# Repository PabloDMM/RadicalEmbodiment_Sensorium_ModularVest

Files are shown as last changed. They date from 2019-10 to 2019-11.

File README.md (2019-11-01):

# Sensorium_ModularVest
***Sensorium (Radical Embodiment)*** is a project consisting in a modular illuminated vest that can display abstract information.

***This Repository contains all the files needed to reproduce the device.***
***This Repository is merely destined to the technological part of the project.***
***This Repository makes use of the programs: EagleCad, Arduino IDE, Tensorflow.***

If any other information is needed, please contact with the repository owner (pablodmm.isp@gmail.com) or any of the participants of the project.

## Description

Sensorium is the first prototype for the material tech part of the final project of Gabriel G. Regués. It consist on a modular illuminated vest conformed by an unespecific number of *Arduino* based modules connected to display specific information through an I2C net.

***Watch the Video by pressing the header:***

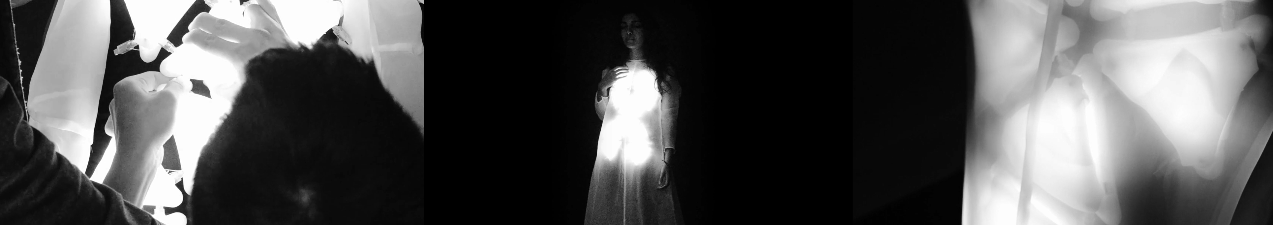
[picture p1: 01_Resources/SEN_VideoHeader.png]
Watch the video (https://vimeo.com/330038499)


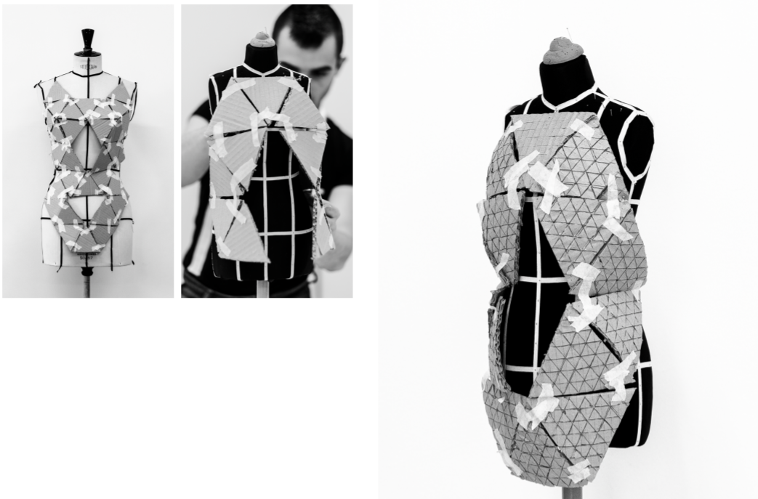
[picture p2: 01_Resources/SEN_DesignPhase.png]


As escribed in the final essay:

*Sensorium - Radical Embodiment - es un proyecto colectivo desarrollado en colaboración por Jaime Remirez de Ganuza, Gonzalo de Torres Sainz, Pablo de Miguel Morales y Gabriel G. Regües.
Este proyecto es una continuación de un proyecto anterior realizado a finales del 2018 por Jaime y Gabriel, al que llamaron El Culto de la Subversión1 y en el que se formularon algunas preguntas que siguen formando parte de este trabajo. El Culto de la Subversión se enfrentaba a la idea de un grupo social en el que se había impuesto una prenda única y se especulaba sobre las posibilidades de transformación de la misma, a medida que los integrantes entraban o dejaban de formar parte del grupo. Los diseñadores investigaban de qué manera cada individuo podía servir creativamente a la creación de los símbolos de representación de un colectivo organizado de forma igualitaria y horizontal. El proyecto se articuló en torno a la creación de una prenda modular, formada por un número determinado de piezas que podían combinarse de distintas maneras. Estas piezas estaban formadas en tela, en la que habían sido impresos unos elementos gráficos. La posibilidades de reconfiguración de la prenda daban lugar a distintas variaciones, tanto en el aspecto formal como gráfico, que representaban la integración o salida de individuos en el grupo.*

## System Overview

The system is based on a I2C net of *Arduino Nano* based modules that control 10 WS212B RGB LEDs each. The aim is to display abstract information incoming from a *Tensorflow* software system running on a PC based on global population database.

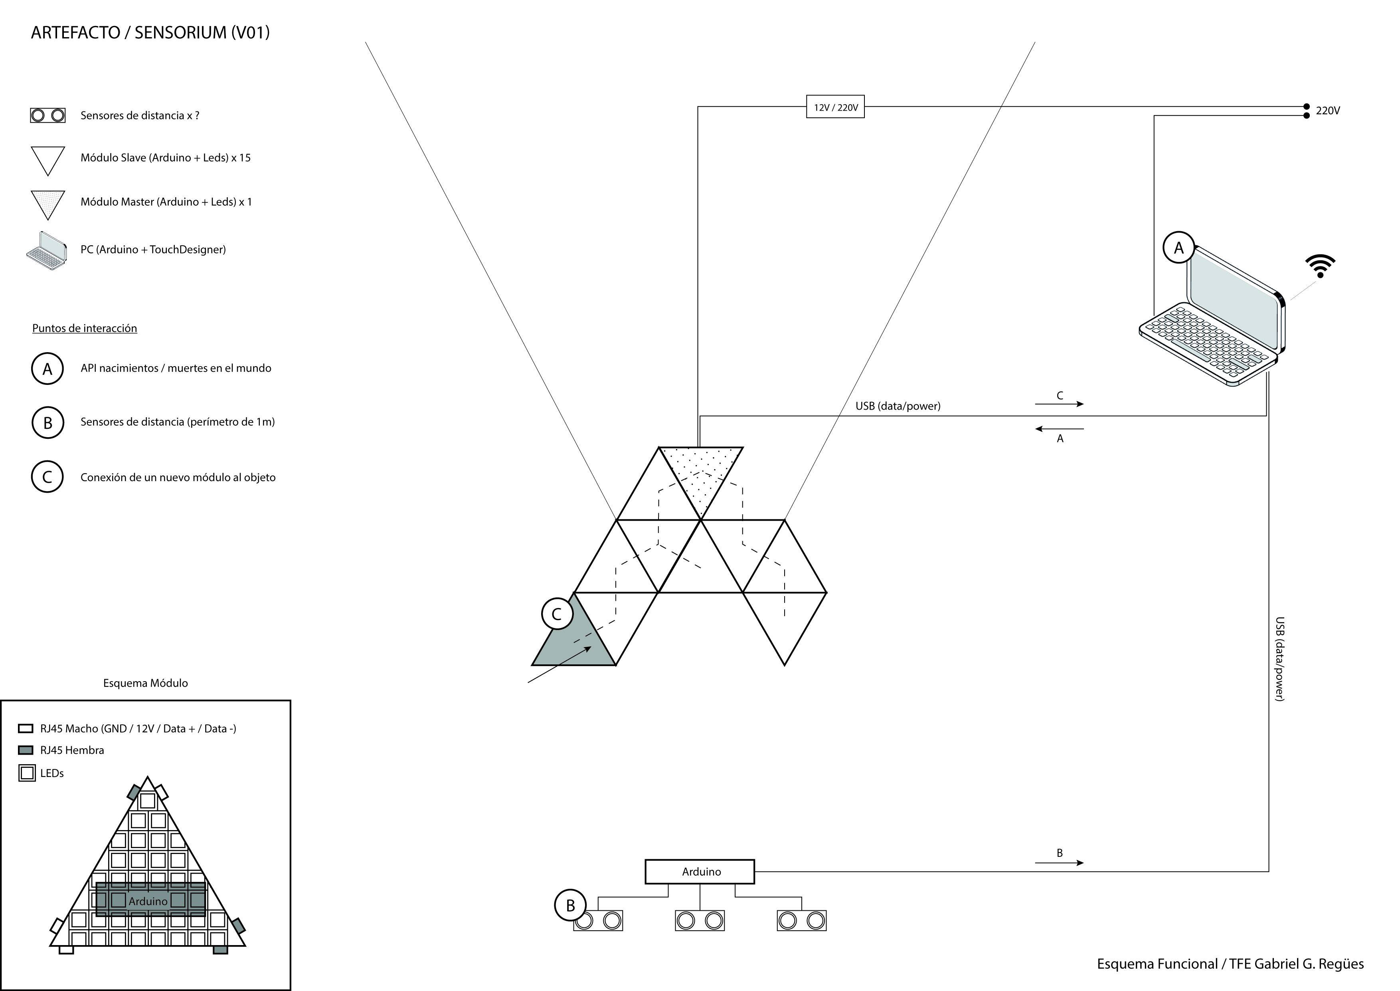
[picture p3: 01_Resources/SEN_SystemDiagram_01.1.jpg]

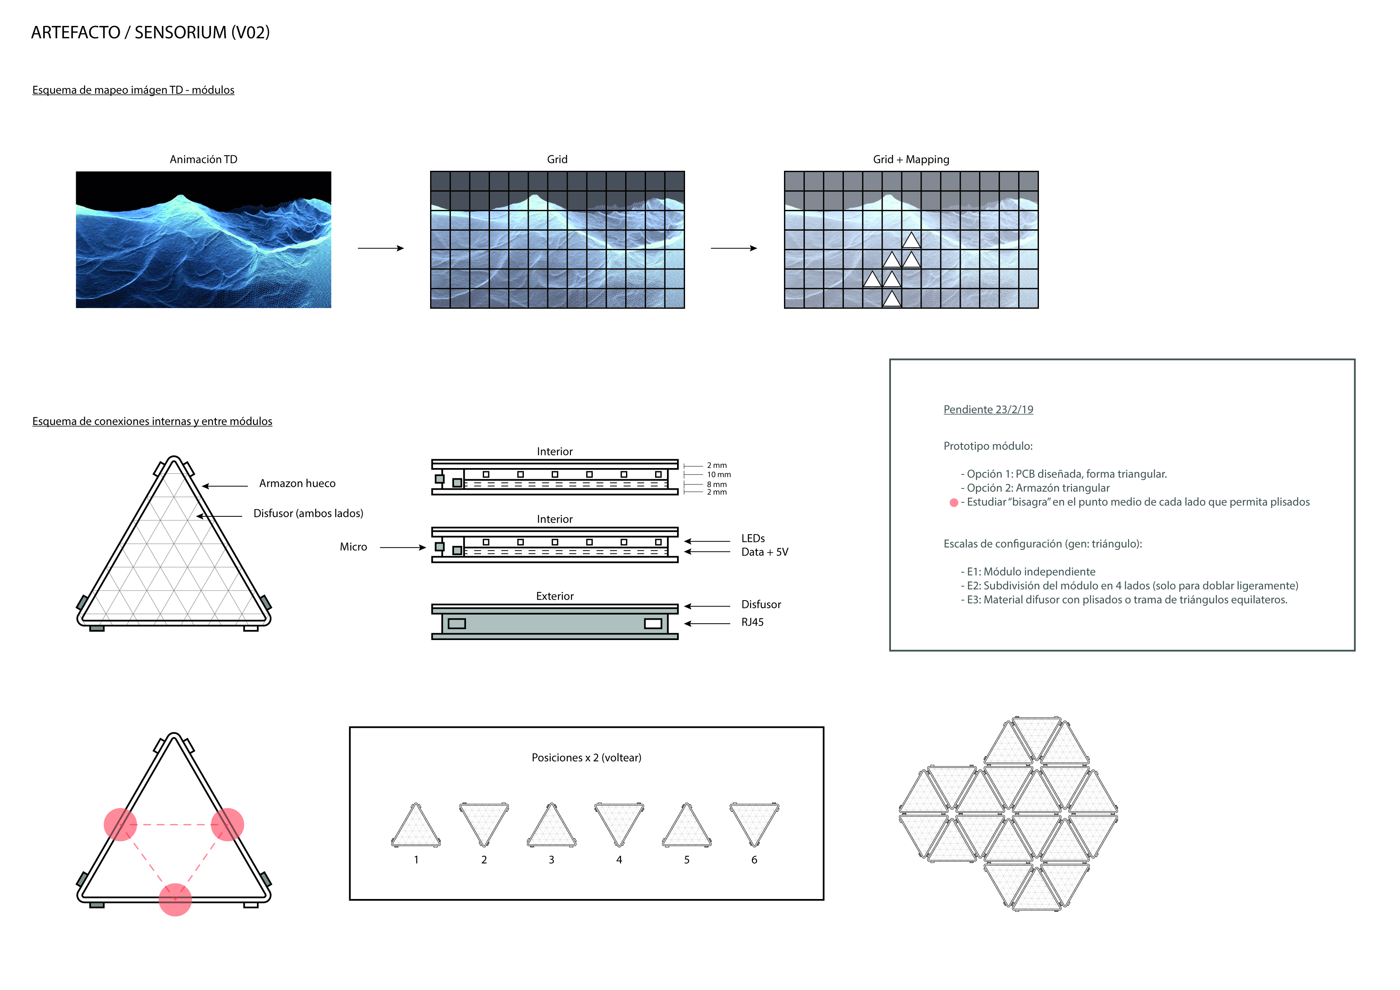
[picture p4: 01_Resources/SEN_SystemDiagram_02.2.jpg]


### Arduino Modules

The Arduino Modules are named *IED_GR_Module_Rev_02*. It consist on a triangular PCB equipped with an *Arduino Nano*, a I2C identification resistor array (8bit based, 254 possible directions) and 10 WS2812B RGB LEDs.

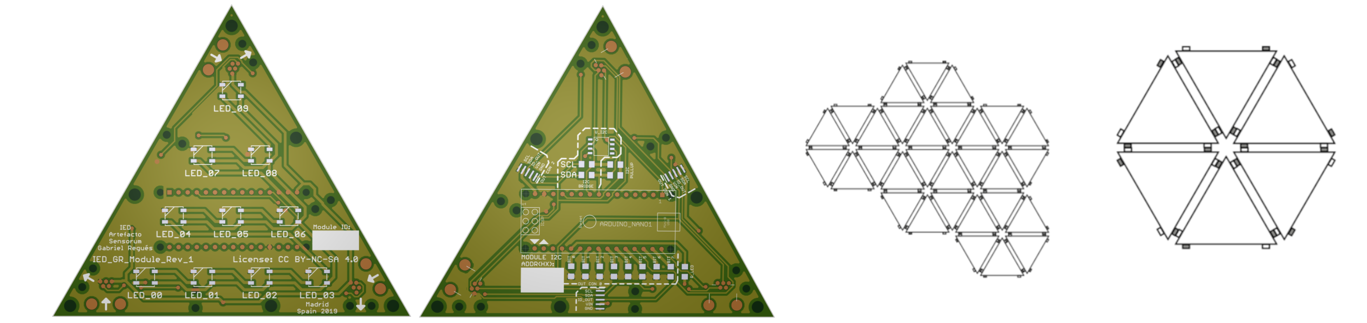
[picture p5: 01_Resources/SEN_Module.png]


Aditionally, it has 3 redundant pairs of miniUSB connectors (both male and female) destined to interconnect an undefined number of modules. The signals present in this connectors are:

* 5V (VCC)
* GND
* SDA (I2C)
* SCL (I2C)

#### Bill of Materials (BOM)
The Module is conformed by the following elements:

* PCB				1	Printed-Circuit-Board	
* Arduino Nano		1	Microprocesador	
* WS2812b  SMD5050	10	RGB LEDs	WS2812B
* Mini USB B female	3	Mini USB B female	
* Mini USB B male	3	Mini USB B male	
* R_DIR_[0:7]		7	10kOhm Resistor. Footprint 1206. Sets the I2C device direction.	
* R_I2C_[0:1]		2	10kOhm Resistor. Footprint 1206. I2C Bus PullUps	

#### PCB Characterictics
The Characteristics of the PCB are the following:

* Dimensions (Square):  100 x 87 mm
* Thickness:            1.6 mm
* Layers:               2 (TOP y BOT)
* Color PCB:            White
* Color Serigraphy:     Black

The PCBs were made through *Elecrow* ( https://www.elecrow.com/ )

#### Prototype Problems
The prototypes have a number of critical mistakes, that can be fixed through the following procedure:

* Step 1: Cut the Signal marked in Blue thorugh the points indicated.
* Step 2: Bypass the signal marked in Green.

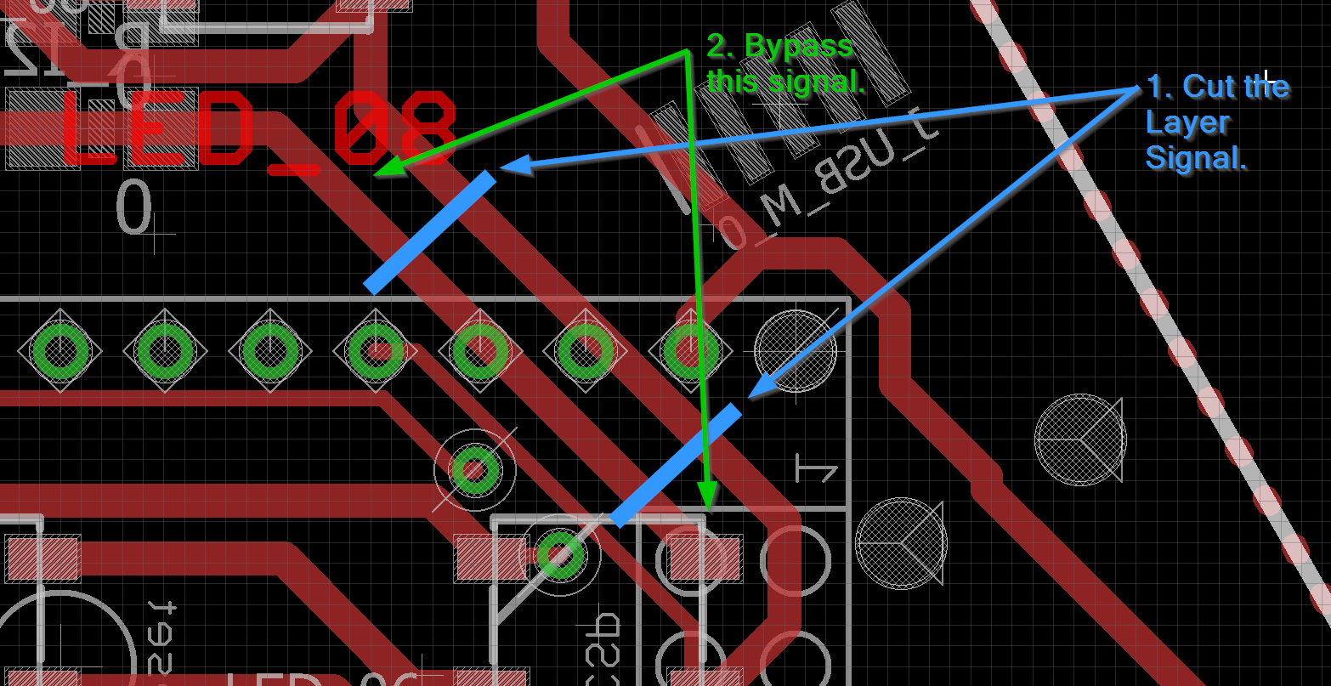
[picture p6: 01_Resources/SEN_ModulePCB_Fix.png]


Anycase, if anyone plans to rebuild the devices, we strongly encourage to contact us to apply a large number of fixes.

#### Software
The modules make use of two *Arduino* sowfwares, one for *I2C Slave* and another for *I2C Master*:

* _SEN_ModuleI2cMaster.ino_: Distributed a long array of data incoming for USB Serial *Tensorflow* Software running in a PC. Only One module of the net performs as *Master*.

* _SEN_ModuleI2cSlave.ino_: Manages 10 WS2812B REG LEDs based of I2C incoming Data.

Additionally, a large number of preliminary *Arduino* programs can be found in the repository, as part of the development.

Please notice the Arduino Nano used need the *Old ATMega328 Bootloader*, not the new one.

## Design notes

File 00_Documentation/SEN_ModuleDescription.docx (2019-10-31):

SENSORIUM_Module_Rev_01

1. Introducción

Este documento recoge una descripción general de la PCB de desarrollo SENSORIUM_Module_Rev_01 , que forma parte del proyecto Sensorium para el TFE de Gabriel G. Regües, alumno del Título Superior de Diseño Gráfico en IED Madrid. Este proyecto se ha hecho en colaboración con Jaime Remirez de Ganuza, Gonzalo de Torres Sainz y Pablo de Miguel Morales. El proyecto consiste en una Instalación interactiva que, mediante la ficción, se propone especular sobre la práctica del Diseño y su potencial como herramienta de transformación social. Parte de esta instalación se compone de una serie de módulos conectables entre si para formar un wereable. Estos módulos son los que contienen la PCB que se describe en este documento.

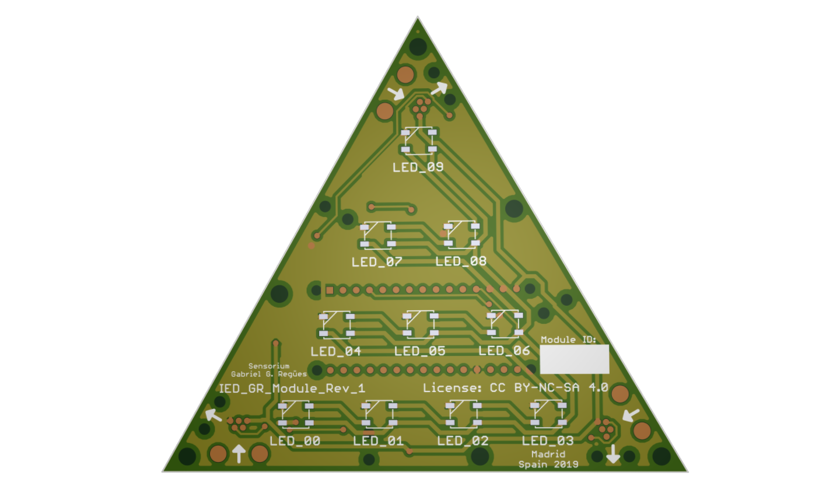
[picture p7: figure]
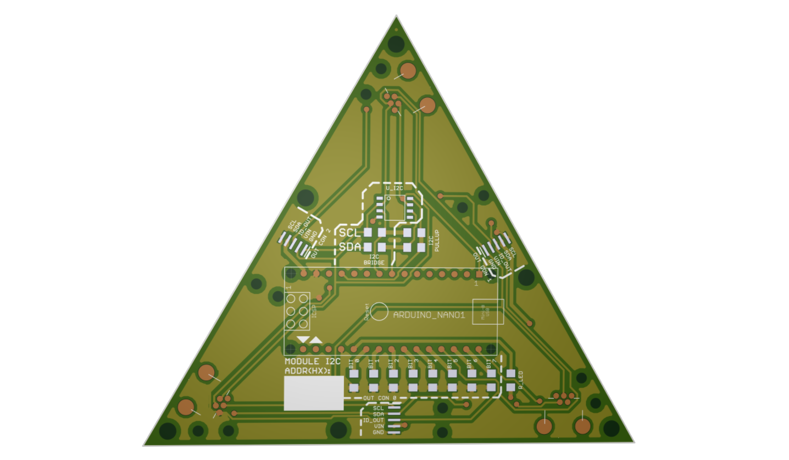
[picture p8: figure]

TOP view BOT view

2. Revisiones

En esta sección se detallan las revisiones realizadas para la SENSORIUM_Module_Rev_01

2.1. Características

En esta sección se describen las características del diseño.

2.1.1. Descripción Funcional

La placa está basada en Arduino Nano. Sus funcionalidades principales son:

- Control de 10 LED WS2812B RGB 5050
- Comunicación i2C entre Arduinos.

2.1.2. Requisitos

2.1.2.1. Arduino Nano

Se ha optado por implementar un Arduino Nano debido a su pequeño tamaño y coste económico.

2.1.1.2.1. Dimensiones y Características Generales

Las características generales de la PCB son:

- Dimensiones: 100 x 87 mm
- Grosor: 1.6 mm
- Capas: 2 (TOP y BOT)
- Color PCB: White
- Color Serigrafía: Black
- Reglas de Diseño Fabricante: Elecrow (http://www.elecrow.com/services/pcb-prototyping/5pcs-2-layer-pcb.html)

2.1.1.2.2. Características Mecánicas

El plano mecánico corresponde a:

(Meter plano)

Donde los DRILLS de sujección son ( ) y se encuentran en las posiciones [x / y] , [x / y] , [x / y] , [x / y] (en mm) siendo la posición [0/0] la esquina inferior izquierda.

2.1.1.3. Bill of Materials (BOM)

Los componentes que forman parte de la PCB están documentados en IED_TFG_BOM_Sensorium.

A continuación se presenta una tabla resumen:

ID | Q. | Descripción | PN
PCB | 1 | Printed-Circuit-Board
Arduino Nano | 1 | Microprocesador
WS2812b SMD5050 | 10 | RGB LEDs | WS2812B
Mini USB B female | 3 | Mini USB B female
Mini USB B male | 3 | Mini USB B male
R_DIR_[0:7] | 7 | 10kOhm Resistor. Footprint 1206. Sets the I2C device direction.
R_I2C_[0:1] | 2 | 10kOhm Resistor. Footprint 1206. I2C Bus PullUps

2.1.1.4. Descripción de Circuitos Concretos

En esta sección se describen en detalle circuitos concretos con un interés particular para el desarrollador.

2.1.1.2.1. Pinout Arduino

Se detalla a continuación la relación de pines del Arduino Nano, que modela las señales de control de todo el circuito.

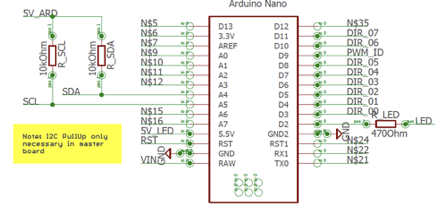
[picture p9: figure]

Arduino IO Pin | Señal | Descripción
D13 | -
3.3V | -
AREF | -
A0 | -
A1 | -
A2 | -
A3 | -
A4 | -
A5 | -
A6 | -
A7 | -
5.5V | 5V_LED
RST | RST
GND | GND
RAW | VIN
D12 | -
D11 | DIR_07
D10 | DIR_06
D9 | PWM_ID
D8 | DIR_05
D7 | DIR_04
D6 | DIR_03
D5 | DIR_02
D4 | DIR_01
D3 | R_LED 470 Ohm
D2 | DIR_00
GND2 | -
RST1 | -
RX1 | -
TXO | -

2.1.1.2.2. Circuito Conectores Mini USB B para conectar módulos

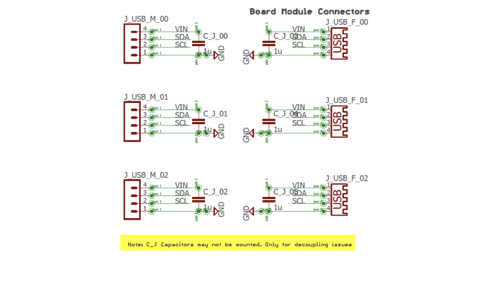
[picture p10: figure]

2.1.1.2.3. Circuito WS2812B RGB LEDs

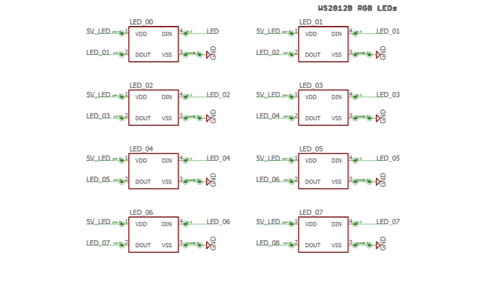
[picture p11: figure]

2.1.1.2.4. Circuito i2C Dir Resistors

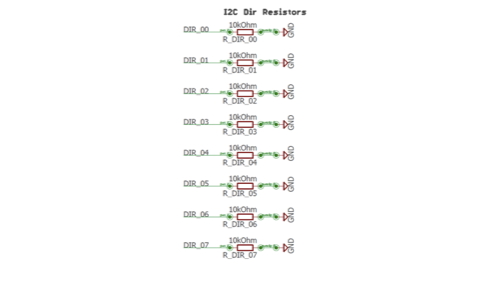
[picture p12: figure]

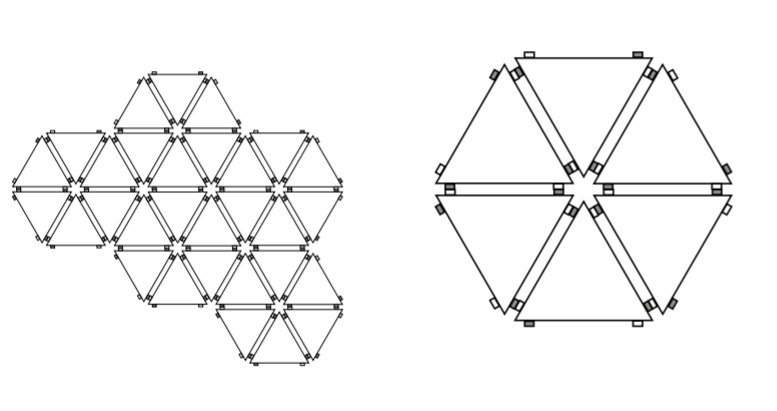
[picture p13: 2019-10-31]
01_Resources/SEN_ModuleConnectionDiagram.png

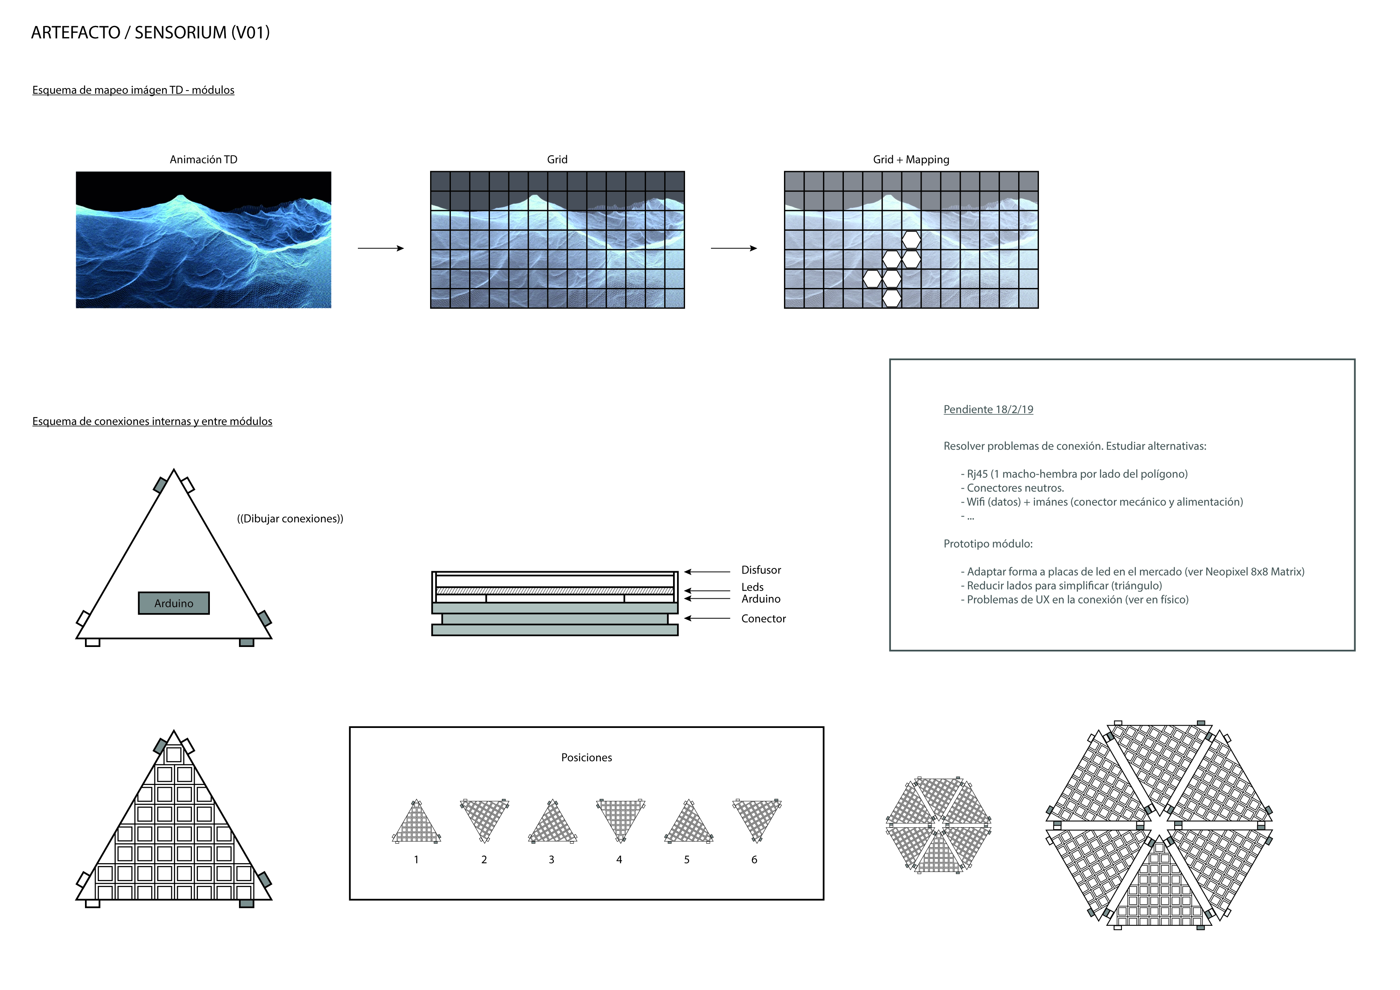
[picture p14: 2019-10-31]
00_Documentation/SEN_SystemDiagram_01.2.jpg

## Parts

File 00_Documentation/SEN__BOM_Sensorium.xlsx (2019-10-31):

BOM |  |  |  |  |  |  | PRICING
ID | Status | Description | Manufacturer | PN | Footprint | Q. | PCs in Pack | Pack Q. | Pack Price (€) | PCs Extra | Total Item | Provider
ELECTRONICS
PCB |  | Printed-Circuit-Board | ELECROW | - | - | 1 | 40 | 01 | €76.82 | 22 | €84.61 | https://www.elecrow.com/pcb-manufacturing.html
ARDUINO NANO |  | Arduino-Nano | TENSTAR ROBOT | - | - | 1 | 40 | 01 | €72.59 | 22 | €72.59 | https://es.aliexpress.com/store/product/Freeshipping-Nano-3-0-controller-compatible-for-arduino-nano-CH340-USB-driver-NO-CABLE/731260_32341832857.html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
WS2812b SMD5050 |  | LEDs | BTF-LIGHTING |  |  | 10 | 500 | 01 | €31.09 | 320 | €31.09 | https://es.aliexpress.com/item/10-1000pcs-WS2812B-4pins-5050-SMD-Black-White-version-WS2812-Individually-Addressable-Digital-RGB-LED-Chip/32453497583.html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
Mini USB tipo B hembra |  | Mini USB tipo B hembra | ZLinKJ |  |  | 3 | 120 | 01 | €7.23 | 66 | €7.23 | https://es.aliexpress.com/store/product/10pcs-Micro-USB-Port-Sockect-Plug-Male-to-Female-Mini-USB-Jack-Front-2Feet-5-PIN/4287020_32888277248.html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
Mini USB tipo B macho |  | Mini USB tipo B macho | OOTDTY |  |  | 3 | 60 | 02 | €31.32 | 66 | €62.64 | https://es.aliexpress.com/store/product/1-PC-Short-USB2-0-Extension-Cable-A-Male-to-Mini-5-pin-B-Male-USB/2793067_32803810965.html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
 |  |  |  |  |  | 0 | 1 | 00 | €0.00 | 0 | €0.00
 |  |  |  |  |  | 0 | 1 | 00 | €0.00 | 0 | €0.00
 |  |  |  |  |  | 0 | 1 | 00 | €0.00 | 0 | €0.00
FRAME
 |  |  |  |  |  | 0 | 1 | 00 | €0.00 | 0 | €0.00
 |  |  |  |  |  | 0 | 1 | 00 | €0.00 | 0 | €0.00
 |  |  |  |  |  | 0 | 1 | 00 | €0.00 | 0 | €0.00
DIFUSSER
 |  |  |  |  |  | 0 | 1 | 00 | €0.00 | 0 | €0.00
 |  |  |  |  |  | 0 | 1 | 00 | €0.00 | 0 | €0.00
 |  |  |  |  | Total Expenses |  |  |  |  |  | €258.16
 |  |  |  |  | System Q. | 18
*Envío desde Madrid 5-7 días
Caja: silicona para molde, resina, filoflex...
Difusor: Tela, plástico, gel, vinilo....

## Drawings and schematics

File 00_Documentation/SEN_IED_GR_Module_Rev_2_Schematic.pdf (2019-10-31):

# 0 GND GND

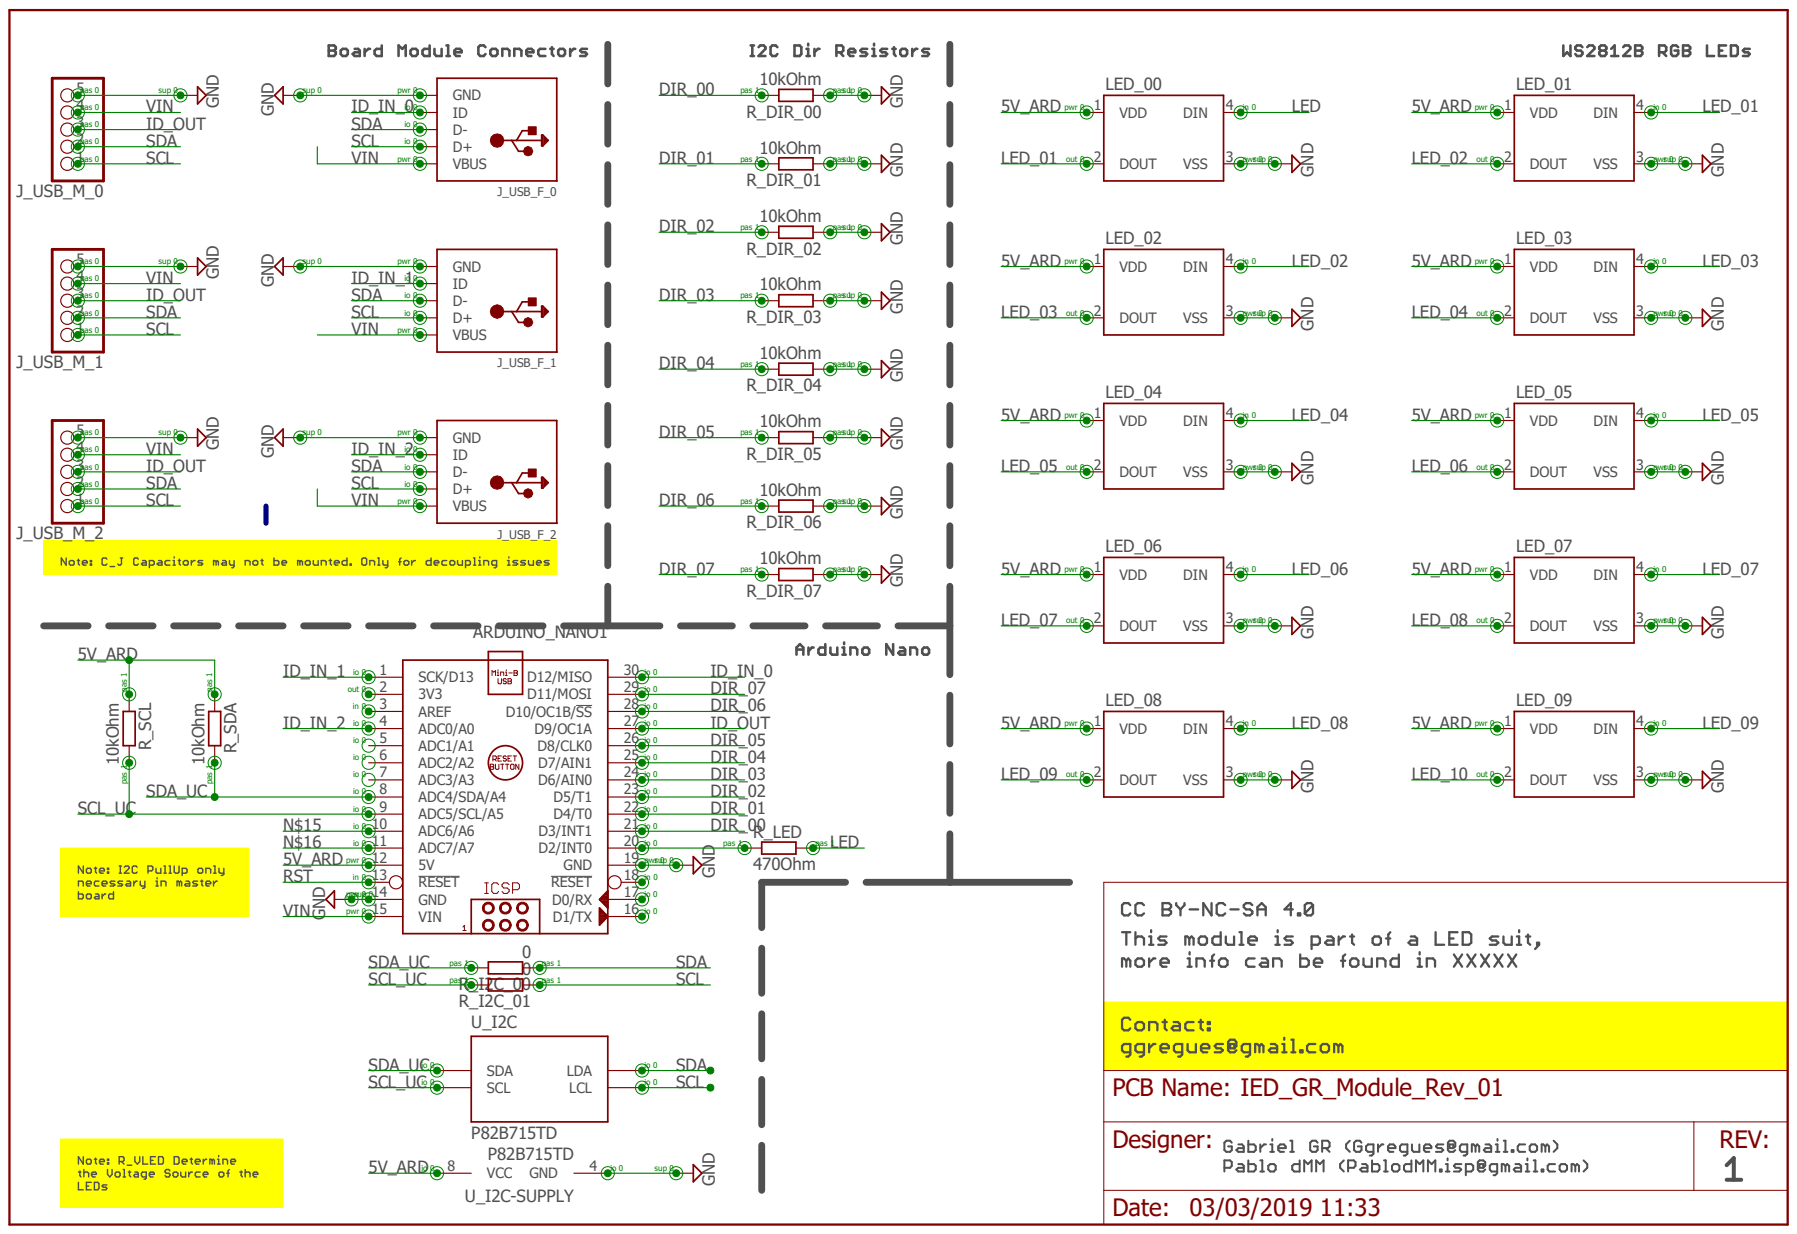
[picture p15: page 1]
470Ohm; 10kOhm; GND; GND GND; GND GND GND; VDD 1; DOUT 2; VSS; DIN; 4 LED_00 R_SCL; R_SDA; 4 LED_01; 4 LED_02; 4 LED_03; 4 LED_04; 4 LED_05; 4 LED_06; 4 LED_07; 4 LED_08; 4 LED_09; R_LED; R_DIR_00; R_DIR_01; R_DIR_02; R_DIR_03; R_DIR_04; R_DIR_05; R_DIR_06; R_DIR_07; 17 RESET; 18 GND; 19 D2/INT0; 20 D3/INT1; 23 D6/AIN0; 24 D7/AIN1; 25 D8/CLK0; 28 D11/MOSI; 29 D12/MISO; 30 SCK/D13 1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

GND GND GND 10kOhm 10kOhm GND GND GND GND GND GND GND GND GND

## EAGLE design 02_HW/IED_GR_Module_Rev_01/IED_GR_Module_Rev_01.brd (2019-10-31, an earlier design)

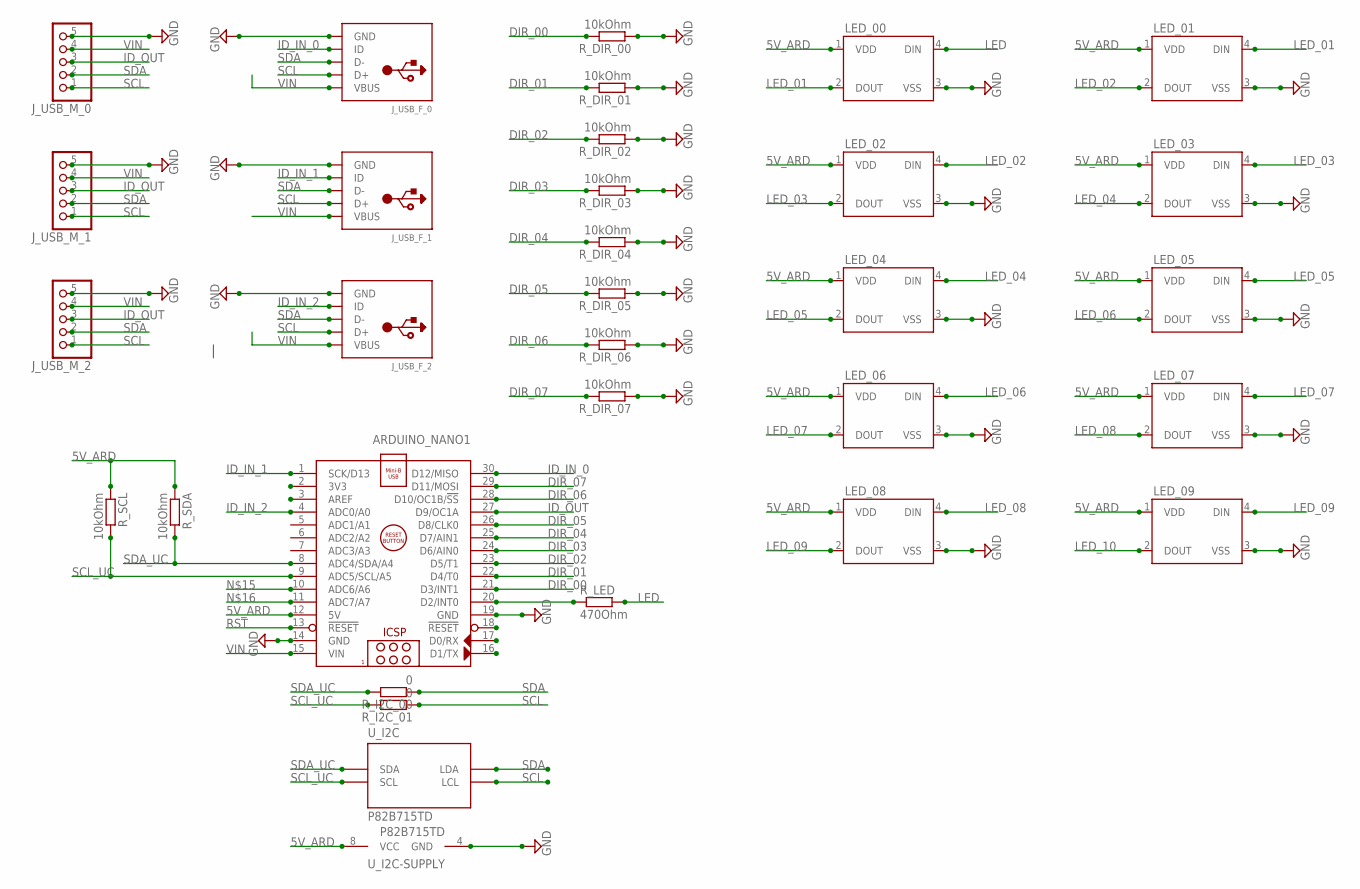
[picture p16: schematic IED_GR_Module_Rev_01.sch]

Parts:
ARDUINO_NANO1: ARDUINO_NANO
J_USB_F_0, J_USB_F_1, J_USB_F_2: USBTHM; USB-MINIB-THM
J_USB_M_0, J_USB_M_1, J_USB_M_2: HEADER-1X51.27MM; 1X05_1.27MM
LED_00, LED_01, LED_02, LED_03, LED_04, LED_05, LED_06, LED_07, LED_08, LED_09: WS2812B
R_DIR_00, R_DIR_01, R_DIR_02, R_DIR_03, R_DIR_04, R_DIR_05, R_DIR_06, R_DIR_07: 10kOhm; R1206
R_I2C_00, R_I2C_01: 0; R1206
R_LED: 470Ohm; R1206
R_SCL: 10kOhm; R1206
R_SDA: 10kOhm; R1206
U_I2C: P82B715TD; SOIC-8

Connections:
5V_ARD: ARDUINO_NANO1.12 (5V), LED_00.1 (VDD), LED_01.1 (VDD), LED_02.1 (VDD), LED_03.1 (VDD), LED_04.1 (VDD), LED_05.1 (VDD), LED_06.1 (VDD), LED_07.1 (VDD), LED_08.1 (VDD), LED_09.1 (VDD), R_SCL.1, R_SDA.1, U_I2C.8 (VCC)
DIR_00: ARDUINO_NANO1.21 (D3/INT1), R_DIR_00.2
DIR_01: ARDUINO_NANO1.22 (D4/T0), R_DIR_01.2
DIR_02: ARDUINO_NANO1.23 (D5/T1), R_DIR_02.2
DIR_03: ARDUINO_NANO1.24 (D6/AIN0), R_DIR_03.2
DIR_04: ARDUINO_NANO1.25 (D7/AIN1), R_DIR_04.2
DIR_05: ARDUINO_NANO1.26 (D8/CLK0), R_DIR_05.2
DIR_06: ARDUINO_NANO1.28 (D10/OC1B/!SS), R_DIR_06.2
DIR_07: ARDUINO_NANO1.29 (D11/MOSI), R_DIR_07.2
GND: ARDUINO_NANO1.14 (GND), ARDUINO_NANO1.19 (GND), J_USB_F_0.GND, J_USB_F_1.GND, J_USB_F_2.GND, J_USB_M_0.5, J_USB_M_1.5, J_USB_M_2.5, LED_00.3 (VSS), LED_01.3 (VSS), LED_02.3 (VSS), LED_03.3 (VSS), LED_04.3 (VSS), LED_05.3 (VSS), LED_06.3 (VSS), LED_07.3 (VSS), LED_08.3 (VSS), LED_09.3 (VSS), R_DIR_00.1, R_DIR_01.1, R_DIR_02.1, R_DIR_03.1, R_DIR_04.1, R_DIR_05.1, R_DIR_06.1, R_DIR_07.1, U_I2C.4 (GND)
ID_IN_0: ARDUINO_NANO1.30 (D12/MISO), J_USB_F_0.ID
ID_IN_1: ARDUINO_NANO1.1 (SCK/D13), J_USB_F_1.ID
ID_IN_2: ARDUINO_NANO1.4 (ADC0/A0), J_USB_F_2.ID
ID_OUT: ARDUINO_NANO1.27 (D9/OC1A), J_USB_M_0.3, J_USB_M_1.3, J_USB_M_2.3
LED: LED_00.4 (DIN), R_LED.2
LED_01: LED_00.2 (DOUT), LED_01.4 (DIN)
LED_02: LED_01.2 (DOUT), LED_02.4 (DIN)
LED_03: LED_02.2 (DOUT), LED_03.4 (DIN)
LED_04: LED_03.2 (DOUT), LED_04.4 (DIN)
LED_05: LED_04.2 (DOUT), LED_05.4 (DIN)
LED_06: LED_05.2 (DOUT), LED_06.4 (DIN)
LED_07: LED_06.2 (DOUT), LED_07.4 (DIN)
LED_08: LED_07.2 (DOUT), LED_08.4 (DIN)
LED_09: LED_08.2 (DOUT), LED_09.4 (DIN)
LED_10: LED_09.2 (DOUT)
LED_OUT: ARDUINO_NANO1.20 (D2/INT0), R_LED.1
RST: ARDUINO_NANO1.13 (!RESET)
SCL: J_USB_F_0.D+, J_USB_F_1.D+, J_USB_F_2.D+, J_USB_M_0.1, J_USB_M_1.1, J_USB_M_2.1, R_I2C_01.1, U_I2C.2 (LCL)
SCL_UC: ARDUINO_NANO1.9 (ADC5/SCL/A5), R_I2C_01.2, R_SCL.2, U_I2C.3 (SCL)
SDA: J_USB_F_0.D-, J_USB_F_1.D-, J_USB_F_2.D-, J_USB_M_0.2, J_USB_M_1.2, J_USB_M_2.2, R_I2C_00.1, U_I2C.7 (LDA)
SDA_UC: ARDUINO_NANO1.8 (ADC4/SDA/A4), R_I2C_00.2, R_SDA.2, U_I2C.6 (SDA)
VIN: ARDUINO_NANO1.15 (VIN), J_USB_F_0.VBUS, J_USB_F_1.VBUS, J_USB_F_2.VBUS, J_USB_M_0.4, J_USB_M_1.4, J_USB_M_2.4

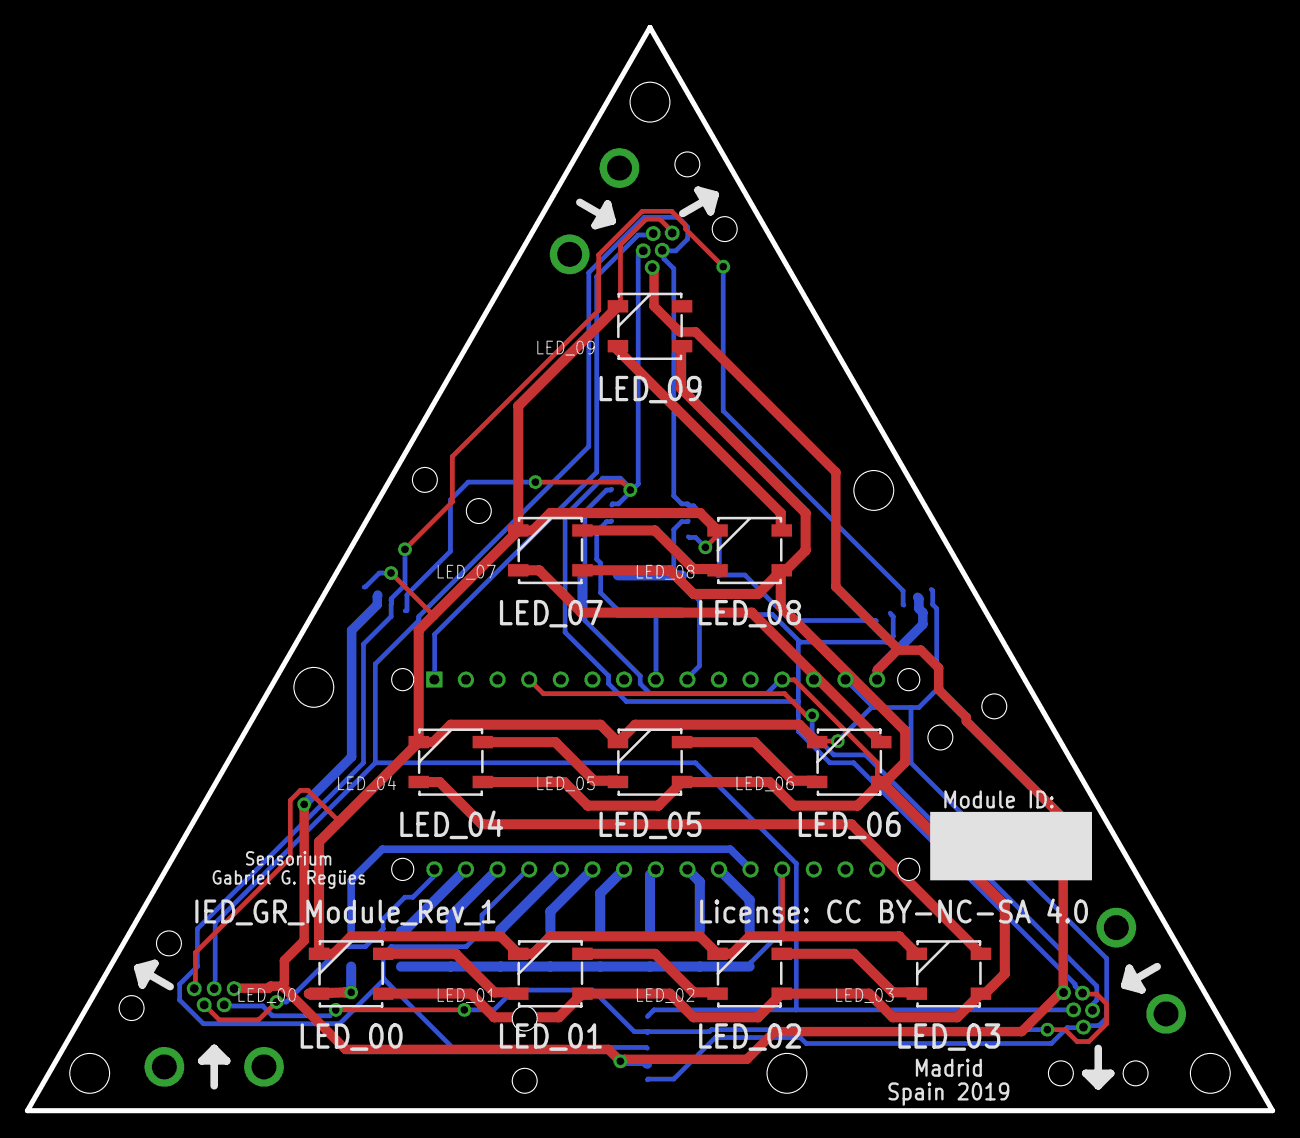
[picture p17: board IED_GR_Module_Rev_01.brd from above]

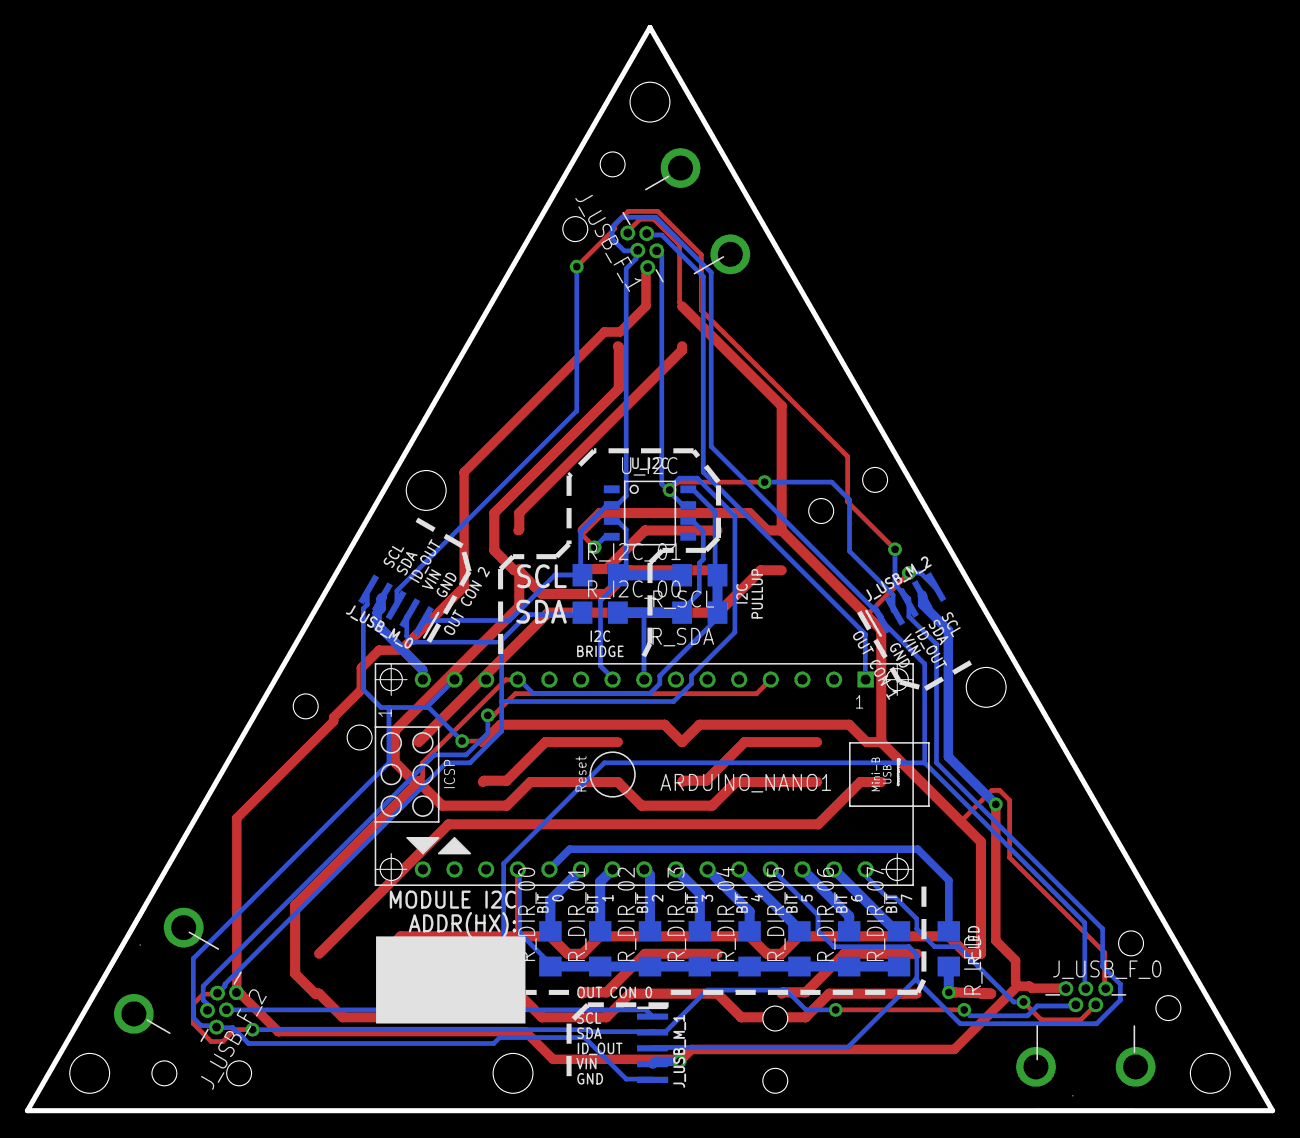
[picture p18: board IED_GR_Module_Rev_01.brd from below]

Board: 2 copper layers, 100.0 x 87.0 mm, 31 parts (21 on the bottom side), 30 nets.

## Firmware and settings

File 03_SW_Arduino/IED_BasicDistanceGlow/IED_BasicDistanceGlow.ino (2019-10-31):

// Library Import
#include <Adafruit_NeoPixel.h>
#include <MIDIUSB.h>
//#include <HCSR04.h>
//#include <hcsr04.h>
#include <HCSR04.h>


// -----------------------------------------------------------------------------------------------------------------------------------------
// ---------------------------------------------------LED Gamma Correction LUT--------------------------------------------------------------
// -----------------------------------------------------------------------------------------------------------------------------------------
const int GC[256] = {
    0,  0,  0,  0,  0,  0,  0,  0,  0,  0,  0,  0,  0,  0,  0,  0,
    0,  0,  0,  0,  0,  0,  0,  0,  0,  0,  0,  0,  1,  1,  1,  1,
    1,  1,  1,  1,  1,  1,  1,  1,  1,  2,  2,  2,  2,  2,  2,  2,
    2,  3,  3,  3,  3,  3,  3,  3,  4,  4,  4,  4,  4,  5,  5,  5,
    5,  6,  6,  6,  6,  7,  7,  7,  7,  8,  8,  8,  9,  9,  9, 10,
   10, 10, 11, 11, 11, 12, 12, 13, 13, 13, 14, 14, 15, 15, 16, 16,
   17, 17, 18, 18, 19, 19, 20, 20, 21, 21, 22, 22, 23, 24, 24, 25,
   25, 26, 27, 27, 28, 29, 29, 30, 31, 32, 32, 33, 34, 35, 35, 36,
   37, 38, 39, 39, 40, 41, 42, 43, 44, 45, 46, 47, 48, 49, 50, 50,
   51, 52, 54, 55, 56, 57, 58, 59, 60, 61, 62, 63, 64, 66, 67, 68,
   69, 70, 72, 73, 74, 75, 77, 78, 79, 81, 82, 83, 85, 86, 87, 89,
   90, 92, 93, 95, 96, 98, 99,101,102,104,105,107,109,110,112,114,
  115,117,119,120,122,124,126,127,129,131,133,135,137,138,140,142,
  144,146,148,150,152,154,156,158,160,162,164,167,169,171,173,175,
  177,180,182,184,186,189,191,193,196,198,200,203,205,208,210,213,
  215,218,220,223,225,228,231,233,236,239,241,244,247,249,252,255 };

// -----------------------------------------------------------------------------------------------------------------------------------------
// ---------------------------------------------------Custom Configuration Structs----------------------------------------------------------
// -----------------------------------------------------------------------------------------------------------------------------------------
// Generated Structures (struct)
struct LEDCOL{
  int red;
  int green;
  int blue;
};

// -----------------------------------------------------------------------------------------------------------------------------------------
// ---------------------------------------------------General Constant Definition-----------------------------------------------------------
// -----------------------------------------------------------------------------------------------------------------------------------------
// PIN DEFINITION
// Digital Pin Definitions
const int  LED    = 2;
const int  SW_0   = 7;
const int  SW_1   = 8;
const int  CH_0   = 0;
const int  CH_1   = 1;
const int  CH_2   = 2;
const int  CH_3   = 3;
const int  MUX_A  = 3;
const int  MUX_B  = 4;
const int  MUX_C  = 5;
const int  MUX_D  = 6;
const int  SW_Q   = 16;

// Constant Definition
const bool ON                 =   1;         // General ON value
const bool OFF                =   0;         // General OFF value

const bool UP                 =   1;         // General UP Fade Direction value
const bool DOWN               =   0;         // General DOWN Fade Direction value

const int LED_INNER_Q        =   4;         
const int LED_OUTER_Q        =   12;


const int FADESTEPS_C         =   100; // GENERAL FadeSteps
const int FADEDELAY_C         =   25; // GENERAL FadeDelay

LEDCOL GEN_OFF    = {GC[255], GC[255],  GC[255]};  // SW_GENERAL OFF LED COLOR
LEDCOL DIST_ON    = {GC[255], GC[0],    GC[200]};  // SW_SCALE ON LED COLOR
LEDCOL DIST_OFF   = {GC[0],   GC[0],     GC[0]};  // SW_MODE ON LED COLOR

const int INNER_LED[4]  = {5, 6, 9, 10};
const int OUTER_LED[12] = {0, 1, 2, 3, 4, 7, 8, 11, 12, 13, 14, 15};

const int THR_DISTANCE  = 40;

bool distanceStatus = OFF;
bool fadeDirection = UP;

Adafruit_NeoPixel LEDSTR = Adafruit_NeoPixel(SW_Q, LED, NEO_RGB + NEO_KHZ800);

HCSR04 DISTANCE(6,7);//initialisation class HCSR04 (trig pin , echo pin)

void setup() {
  // Baudrate Set
  Serial.begin(115200); 
  // LED Stripe Initialization
  LEDSTR.begin();
  LEDSTR.show();
  // Set Pin Modes
  pinMode(MUX_A, OUTPUT);
  pinMode(MUX_B, OUTPUT);
  pinMode(MUX_C, OUTPUT);
  pinMode(MUX_D, OUTPUT);

  //LED_FADE_INIT(0, 0, 0, CH_LED[0][1], CH_LED[0][0], CH_LED[0][2], 10, 80);
}

void loop() {  
  for(int currentStep = 0; currentStep < FADESTEPS_C; currentStep++){
    distanceStatus = get_distanceStatus();
    Serial.println(distanceStatus);
    switch(distanceStatus){
      case OFF:
        //Serial.println("LED OFF");
        LED_GLOWOUT(DIST_OFF, GEN_OFF, FADESTEPS_C, FADEDELAY_C, currentStep, fadeDirection);
        break;
      case ON:     
        //Serial.println("LED ON");
        LED_GLOWOUT(DIST_ON, GEN_OFF, FADESTEPS_C, (FADEDELAY_C/5), currentStep, fadeDirection);
        break;
      break;
    }
  }
  fadeDirection = !fadeDirection;   // Switch Fade Glow Direction
}

void LED_GLOWOUT(LEDCOL COL_ON, LEDCOL COL_OFF, int FS, int FD, int Step, bool fadeDir){
  int RDiff = (COL_OFF.red-COL_ON.red);
  int GDiff = (COL_OFF.green-COL_ON.green);
  int BDiff = (COL_OFF.blue-COL_ON.blue);
  //for(int Step = 0; Step < FS; Step++){
  if(fadeDir == UP){
    for(int i = 0; i < LED_INNER_Q; i++){
      //Serial.println(i);
      LEDSTR.setPixelColor(INNER_LED[i], (COL_OFF.green - ((GDiff/FS)*(FS-Step))), (COL_OFF.red - ((RDiff/FS)*(FS-Step))), (COL_OFF.blue - ((BDiff/FS)*(FS-Step))));
    }
    for(int i = 0; i < LED_OUTER_Q; i++){
      //Serial.println(i);
      LEDSTR.setPixelColor(OUTER_LED[i], (COL_OFF.green - ((GDiff/FS)*(Step))), (COL_OFF.red - ((RDiff/FS)*(Step))), (COL_OFF.blue - ((BDiff/FS)*(Step))));
    }
    LEDSTR.show(); // Update LEDs 
    delay(FD);
  }

  else if(fadeDir == DOWN){
    for(int i = 0; i < LED_INNER_Q; i++){
      //Serial.println(i);
      LEDSTR.setPixelColor(INNER_LED[i], (COL_OFF.green - ((GDiff/FS)*(Step))), (COL_OFF.red - ((RDiff/FS)*(Step))), (COL_OFF.blue - ((BDiff/FS)*(Step))));
    }
    for(int i = 0; i < LED_OUTER_Q; i++){
      //Serial.println(i);
      LEDSTR.setPixelColor(OUTER_LED[i], (COL_OFF.green - ((GDiff/FS)*(FS-Step))), (COL_OFF.red - ((RDiff/FS)*(FS-Step))), (COL_OFF.blue - ((BDiff/FS)*(FS-Step))));
    }
    LEDSTR.show(); // Update LEDs 
    delay(FD);
  }
}

bool get_distanceStatus(){
  bool newState = distanceStatus;
  switch(distanceStatus){
    case OFF:      
      if(DISTANCE.dist() <= THR_DISTANCE){
        Serial.println("OFF to ON");
        newState = ON;
      }
      break;
    case ON:      
      if(DISTANCE.dist() > THR_DISTANCE){
        newState = OFF;
        Serial.println("ON to OFF");
      }
      break;
  }
  return newState;
}

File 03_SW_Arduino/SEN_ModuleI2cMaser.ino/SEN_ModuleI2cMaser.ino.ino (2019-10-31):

/*
 * @file      SEN_ModuleI2cMaser.ino
 * 
 * @authors   Pablo dMM, Gabriel GR (based on Nicholas Zambetti <http://www.zambetti.com> )
 * @date      June 2019
 * @brief     This code correspond to the I2C Slave Master of the Sensorium project, please refer to the repository for more information: https://github.com/PabloDMM/Sensorium_ModularVest
 */

// Libraries
#include <Adafruit_NeoPixel.h>
#include <Wire.h>

// Pin definition
const int LED_PIN    = 2;
const int DIR_00_PIN = 3;
const int DIR_01_PIN = 4;
const int DIR_02_PIN = 5;
const int DIR_03_PIN = 6;
const int DIR_04_PIN = 7;
const int DIR_05_PIN = 8;
const int DIR_06_PIN = 10;
const int DIR_07_PIN = 11;

const byte LEDWHITEINIT       = 50;     // INIT White LED value
const byte LEDWHITE_MINVAR    = 5;      // Minimum variation of LED value
const byte LEDWHITE_MAXVAR    = 50;     // Maximum variation of LED value
const byte LEDWHITE_MINDELAY  = 150;    // Minimum delay between steps
const byte LEDWHITE_MAXDELAY  = 300;    // Mazimum delay between steps

const int FADESTEPS_C         =   25; // GENERAL FadeSteps
const int FADEDELAY_C         =   500; // GENERAL FadeDelay

// Gamma Correction (GC) LUT
const byte GC[256] = {
    0,  0,  0,  0,  0,  0,  0,  0,  0,  0,  0,  0,  0,  0,  0,  0,
    0,  0,  0,  0,  0,  0,  0,  0,  0,  0,  0,  0,  1,  1,  1,  1,
    1,  1,  1,  1,  1,  1,  1,  1,  1,  2,  2,  2,  2,  2,  2,  2,
    2,  3,  3,  3,  3,  3,  3,  3,  4,  4,  4,  4,  4,  5,  5,  5,
    5,  6,  6,  6,  6,  7,  7,  7,  7,  8,  8,  8,  9,  9,  9, 10,
   10, 10, 11, 11, 11, 12, 12, 13, 13, 13, 14, 14, 15, 15, 16, 16,
   17, 17, 18, 18, 19, 19, 20, 20, 21, 21, 22, 22, 23, 24, 24, 25,
   25, 26, 27, 27, 28, 29, 29, 30, 31, 32, 32, 33, 34, 35, 35, 36,
   37, 38, 39, 39, 40, 41, 42, 43, 44, 45, 46, 47, 48, 49, 50, 50,
   51, 52, 54, 55, 56, 57, 58, 59, 60, 61, 62, 63, 64, 66, 67, 68,
   69, 70, 72, 73, 74, 75, 77, 78, 79, 81, 82, 83, 85, 86, 87, 89,
   90, 92, 93, 95, 96, 98, 99,101,102,104,105,107,109,110,112,114,
  115,117,119,120,122,124,126,127,129,131,133,135,137,138,140,142,
  144,146,148,150,152,154,156,158,160,162,164,167,169,171,173,175,
  177,180,182,184,186,189,191,193,196,198,200,203,205,208,210,213,
  215,218,220,223,225,228,231,233,236,239,241,244,247,249,252,255 };


const byte LED_Q        = 10;
const byte MAX_MODULE   = 40;

const byte MIN_I2CDIR   = 8;

const byte ON    = 1;
const byte OFF   = 0;

// Generated Structures (struct)
struct LEDCOL{
  byte red;
  byte green;
  byte blue;
};

// Generated Structures (struct)
struct MODULE{
  byte i2cDir;
  byte detected;
};

// Global Variables
Adafruit_NeoPixel LEDSTR = Adafruit_NeoPixel(LED_Q, LED_PIN, NEO_GRB + NEO_KHZ800);
byte modulesPresent = 1;
//char inputBuffer[LED_Q * MAX_MODULE];
MODULE devices[MAX_MODULE];
LEDCOL GEN_ON    = {GC[255], GC[255],  GC[255]};  
byte ledWhite[LED_Q] = {LEDWHITEINIT, LEDWHITEINIT, LEDWHITEINIT, LEDWHITEINIT, LEDWHITEINIT, LEDWHITEINIT,LEDWHITEINIT,LEDWHITEINIT,LEDWHITEINIT,LEDWHITEINIT};


void setup() {
  Serial.begin(115200);
  Serial.setTimeout(500);
  
  // Initialice devices to OFF
  for(int i = 0; i < MAX_MODULE; i++){
    devices[i].i2cDir = (MIN_I2CDIR + i);
    devices[i].detected = OFF;
  }
  LEDSTR.begin();
  LEDSTR.show(); // Initialize all pixels to 'off'
  Wire.begin(); // join i2c bus (address optional for master)
}


void loop(){
  char inputBuffer[LED_Q * modulesPresent];
  if(Serial.available() > 0) {
    Serial.readBytes(inputBuffer, (LED_Q * modulesPresent));
  }

  // Turn on self lights
  for(int ledIndex = 0; ledIndex < LED_Q; ledIndex ++){
    GEN_ON.red = inputBuffer[ledIndex];
    GEN_ON.green = inputBuffer[ledIndex];
    GEN_ON.blue = inputBuffer[ledIndex];
    LEDSTR.setPixelColor(ledIndex, GC[GEN_ON.green], GC[GEN_ON.red], GC[GEN_ON.blue]);
  }
  LEDSTR.show(); // Update LEDs 

  int modulesCount = 0;
  while(modulesCount < (modulesPresent-1)){
    for(int i2cAddr = 0; i2cAddr < MAX_MODULE; i2cAddr++){
      if(devices[i2cAddr].detected == ON){
          Wire.beginTransmission(i2cAddr); // transmit to device #13
          for(int ledIndex = 0; ledIndex < LED_Q; ledIndex++){
            Wire.write(inputBuffer[ledIndex + (LED_Q * (modulesCount+1))]);
          }
          Wire.endTransmission();    // stop transmitting
          modulesCount++;
      }
    }
  }
    
  modulesPresent = i2cScanner(modulesPresent);
  Serial.println((String)"A1="+modulesPresent);
  delay(10);
}


byte i2cScanner(byte modulesDetected){
  byte nDevices = 0;
  byte error = 0;
  for(int i2cAddr = 0; i2cAddr < MAX_MODULE; i2cAddr++){
      Wire.beginTransmission(i2cAddr);
      int error = Wire.endTransmission();
      if (error == 0)
      {
        if(devices[i2cAddr].detected == OFF){
          devices[i2cAddr].detected = ON;
          modulesDetected++;
        }
      }else{
        if(devices[i2cAddr].detected == ON){
          devices[i2cAddr].detected = OFF;
          modulesDetected--;
        }
      }
  }
  return modulesDetected;
}

void LED_WHITERANDOM(int minVariation, int maxVariation, int FD){
  int variation = 0;
  for(int i = 0; i < LED_Q; i++){
      variation = minVariation + random(maxVariation - minVariation);
      if(random(1)){
          ledWhite[i] = ledWhite[i] - variation;
      }else{
          ledWhite[i] = ledWhite[i] + variation;
      }
      LEDSTR.setPixelColor(i, GC[ledWhite[i]], GC[ledWhite[i]], GC[ledWhite[i]]);
  }
  LEDSTR.show(); // Update LEDs 
  delay(FD);
}

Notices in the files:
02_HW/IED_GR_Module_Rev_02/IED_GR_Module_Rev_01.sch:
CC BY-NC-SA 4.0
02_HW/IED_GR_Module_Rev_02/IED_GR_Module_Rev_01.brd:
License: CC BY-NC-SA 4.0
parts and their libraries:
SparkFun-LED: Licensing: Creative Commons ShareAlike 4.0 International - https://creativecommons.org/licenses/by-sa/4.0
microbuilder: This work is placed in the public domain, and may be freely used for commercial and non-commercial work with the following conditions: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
